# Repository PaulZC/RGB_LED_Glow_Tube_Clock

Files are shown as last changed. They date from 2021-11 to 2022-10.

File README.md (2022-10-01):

# RGB LED Glow Tube Clock

A drop-in replacement PCB for one of the popular LED "Nixie" Glow Tube Clocks available through the usual suppliers.

Features:

* ESP32 WROOM processor - uses WiFi to obtain network time from an NTP server
* 60 x WS2812-2020 2mm x 2mm RGB LEDs - to illuminate the engraved acrylic glow tube digits
* VEML7700 ambient light (lux) sensor - the lux can be used to adjust the LED brightness
* USB-C interface - for 5V power and firmware updates

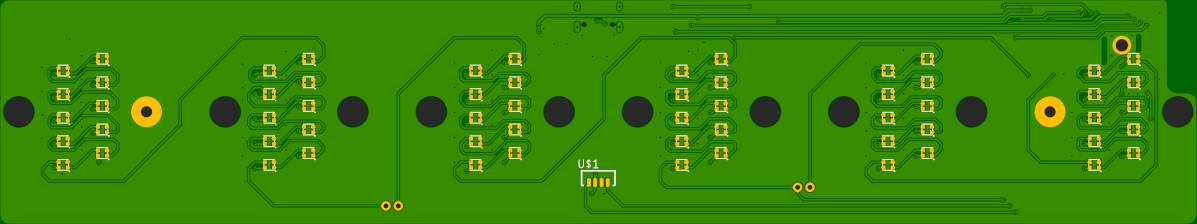
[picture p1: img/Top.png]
Pictured is the top of the circuit board


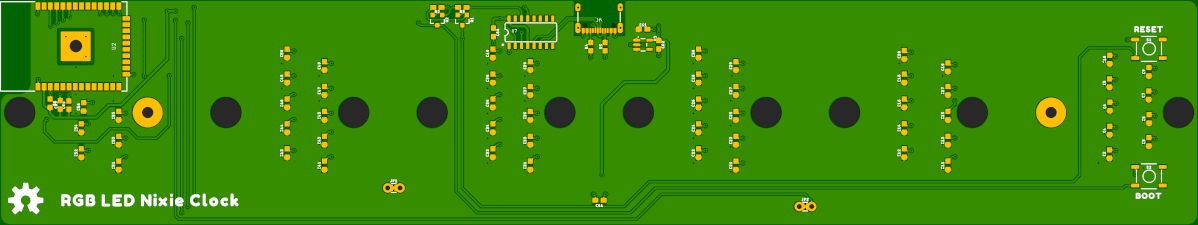
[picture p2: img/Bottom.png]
Pictured is the bottom of the circuit board


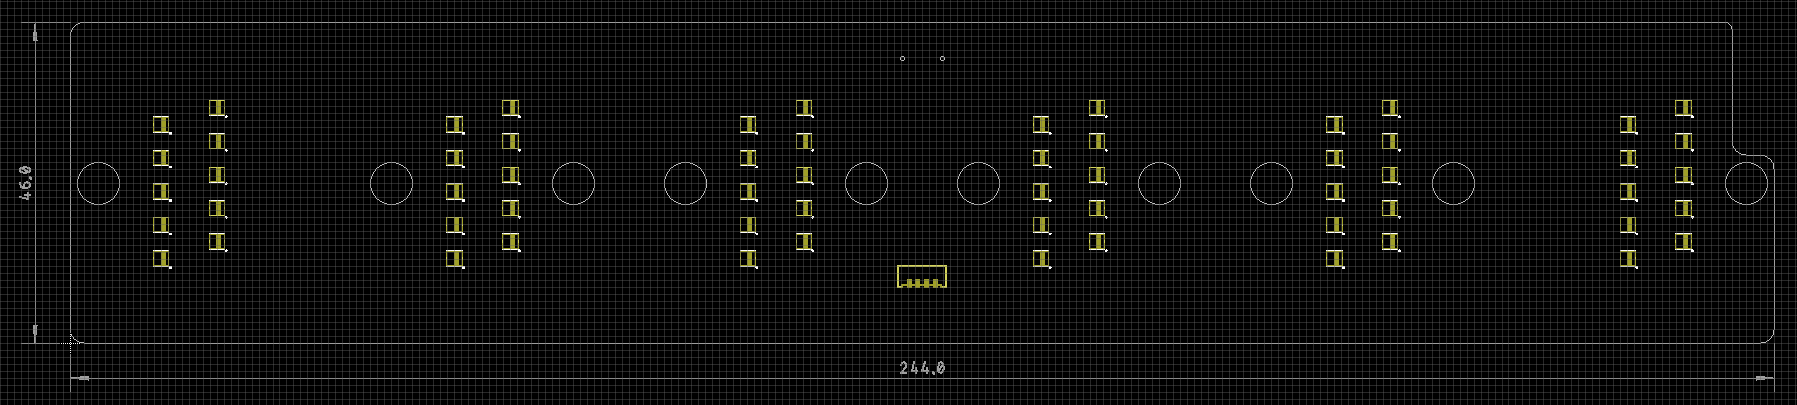
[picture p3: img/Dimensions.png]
Pictured are the circuit board dimensions


Enjoy!

**_Paul_**

## Licence

Please see [LICENSE.md](./LICENSE.md) for details.

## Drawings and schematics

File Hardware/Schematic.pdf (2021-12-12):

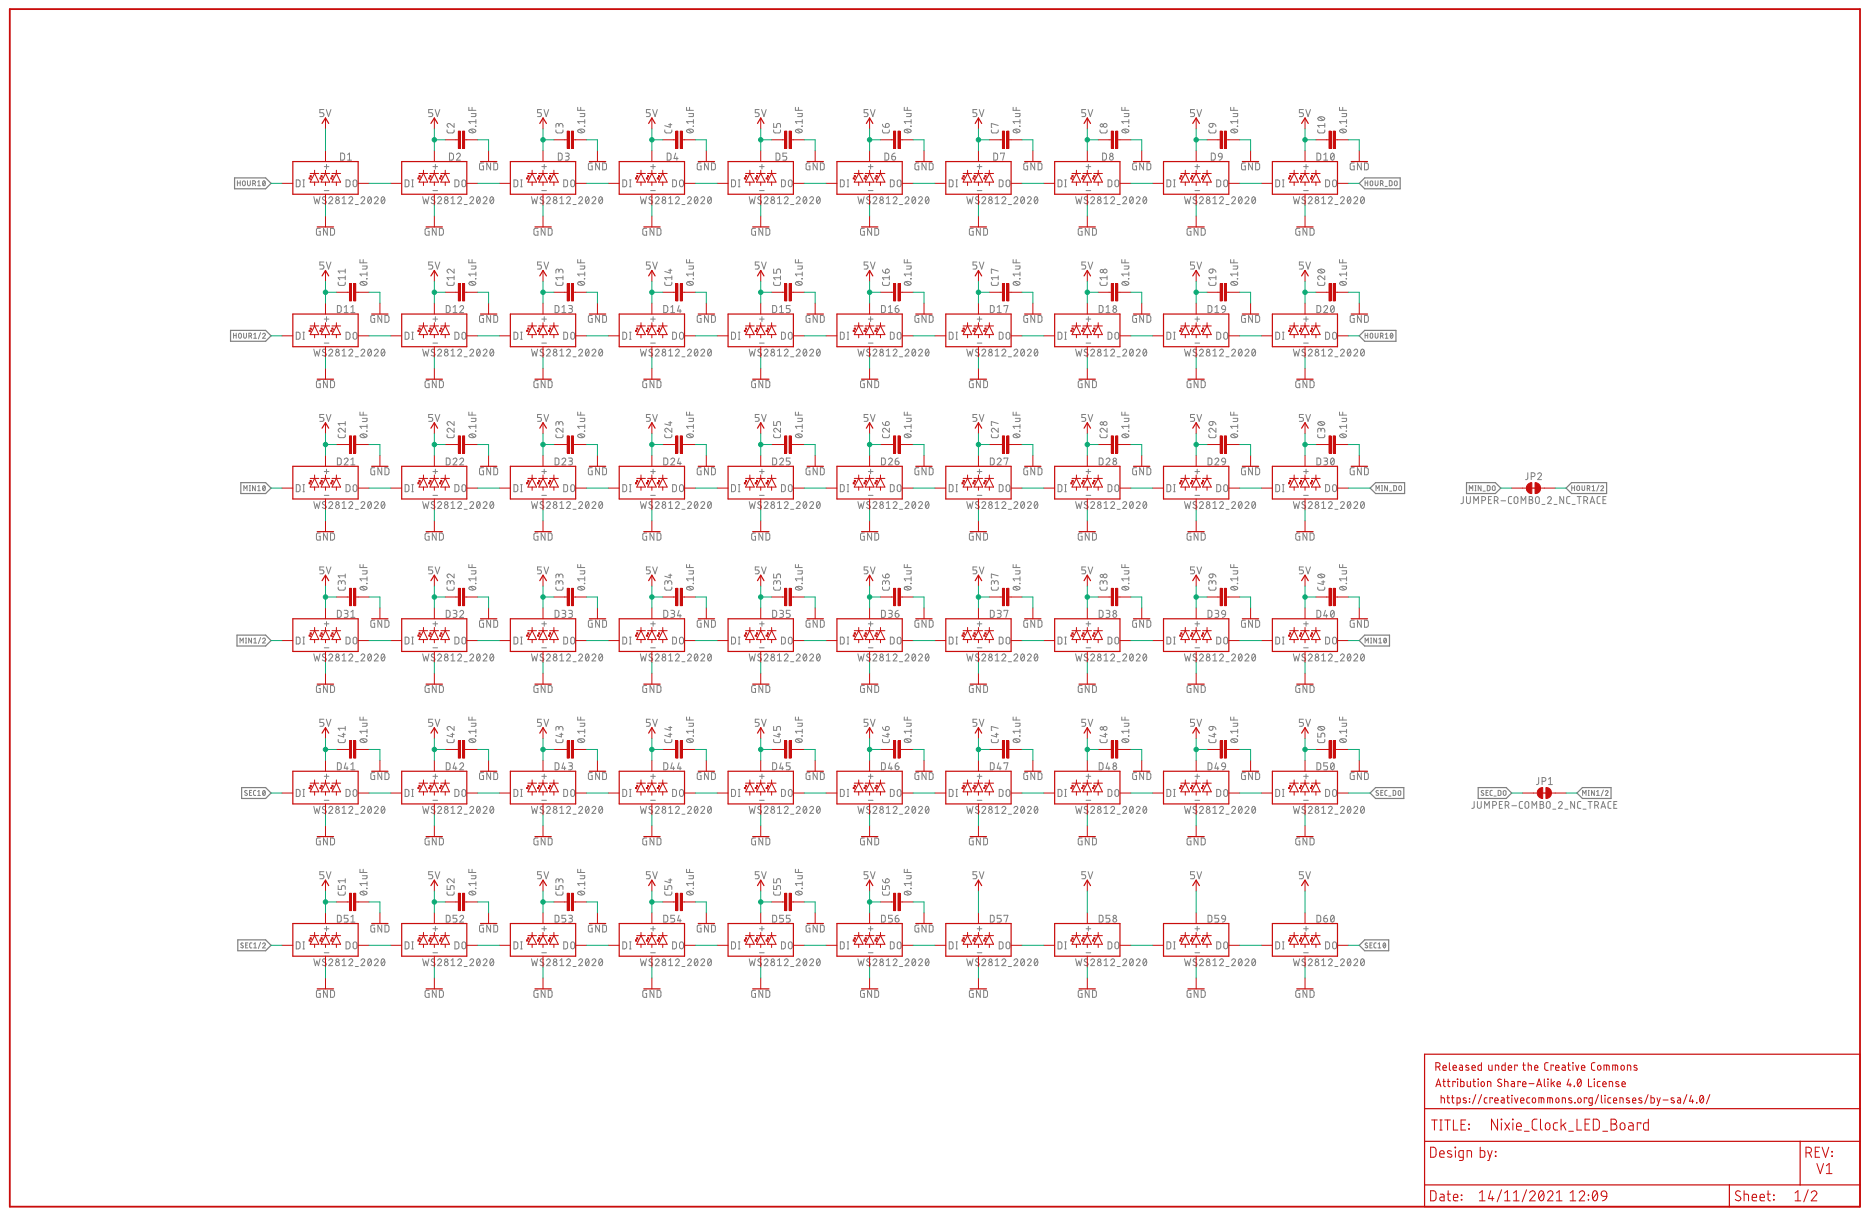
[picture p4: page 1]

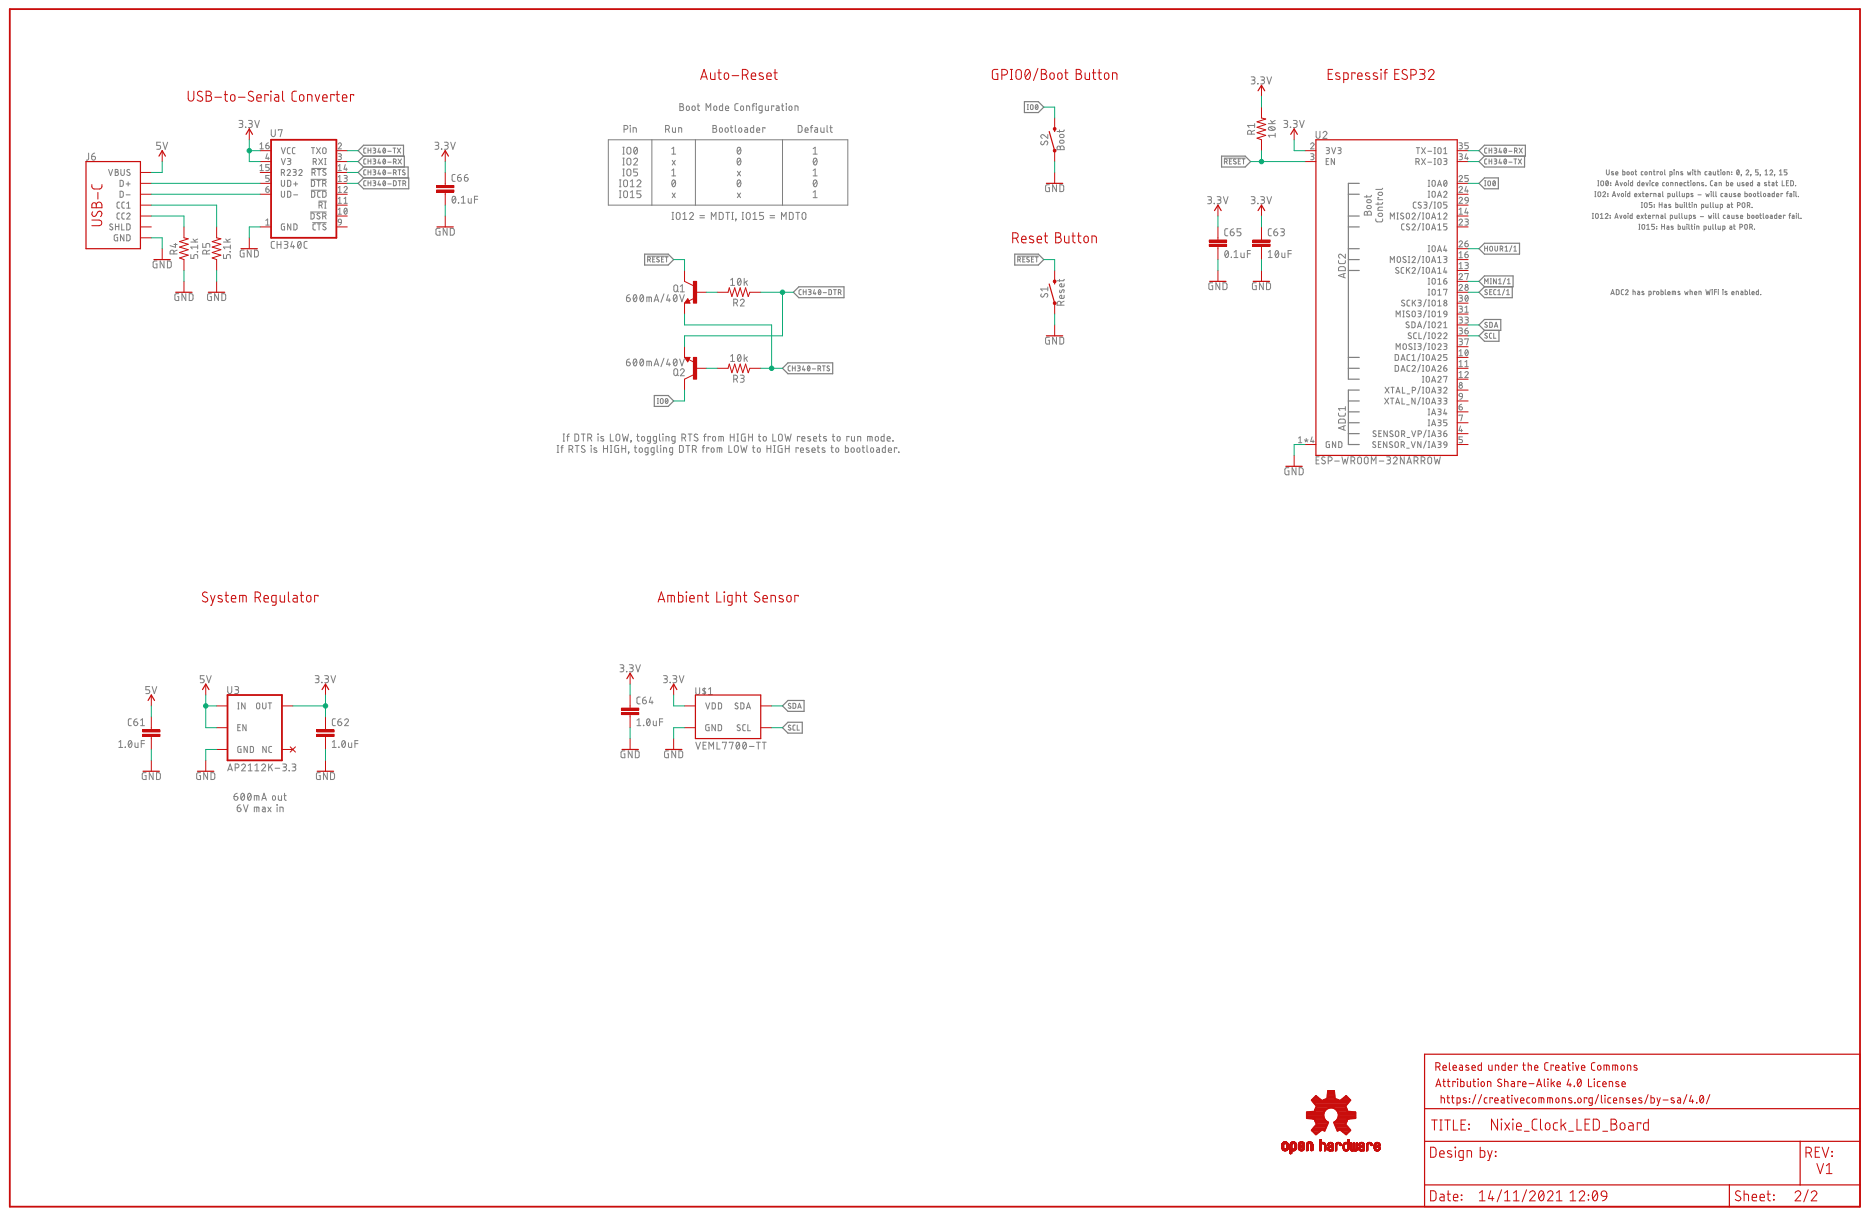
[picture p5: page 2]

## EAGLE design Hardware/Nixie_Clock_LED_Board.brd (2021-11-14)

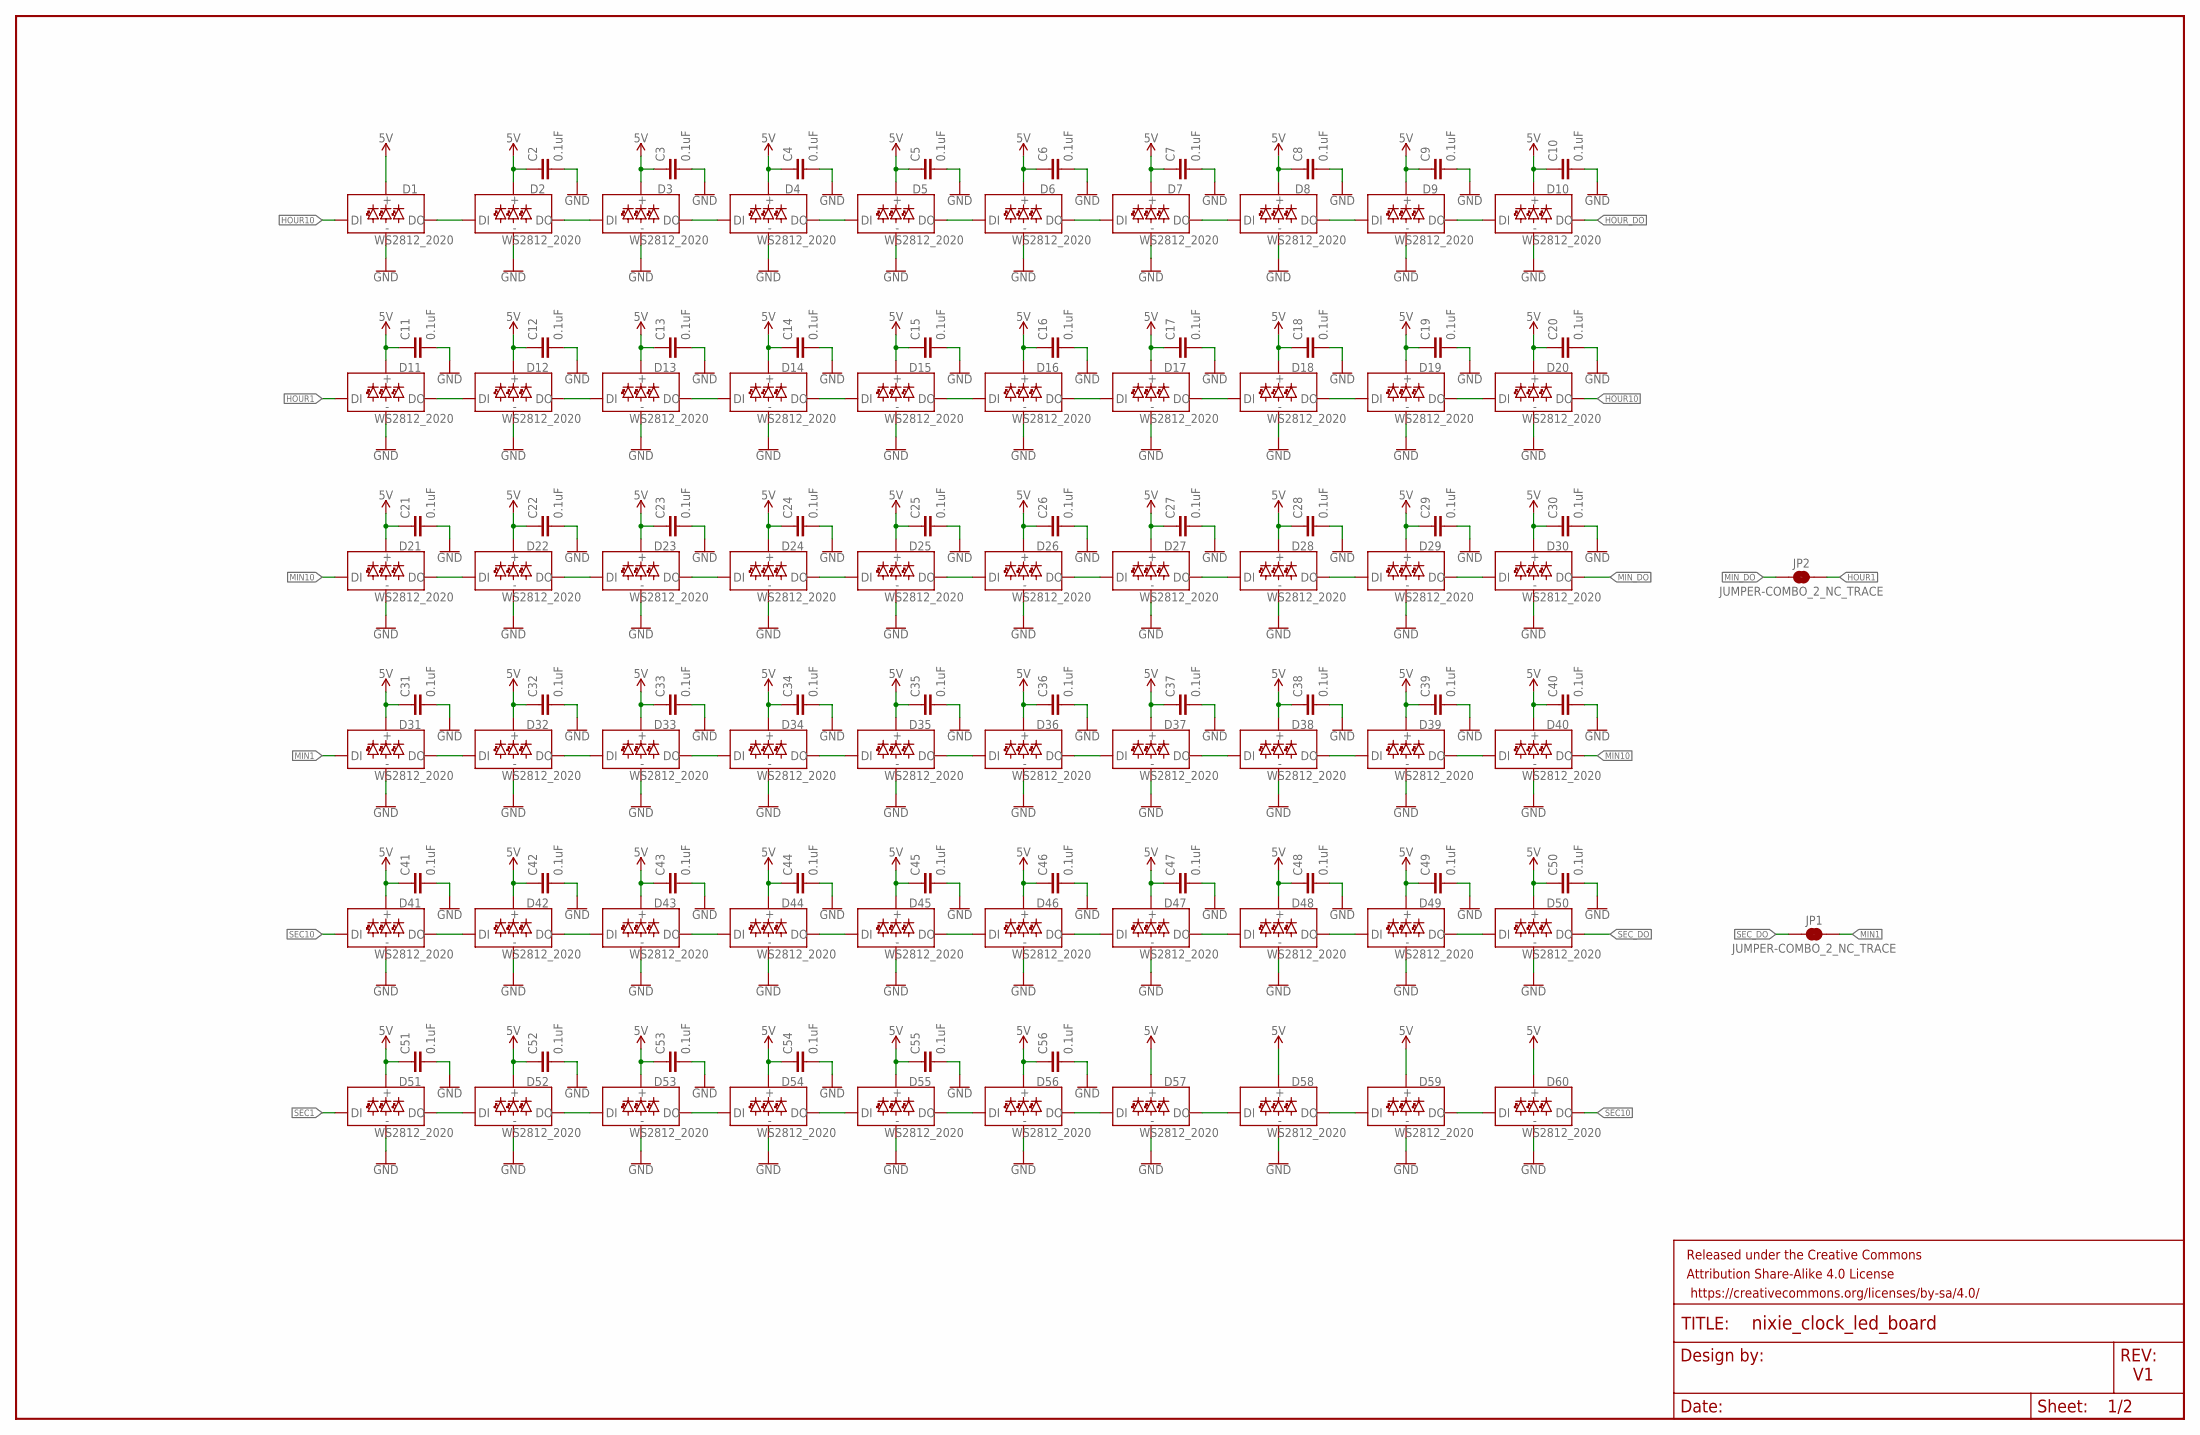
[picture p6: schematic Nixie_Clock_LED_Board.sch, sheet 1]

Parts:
C2, C3, C4, C5, C6, C7, C8, C9, C10, C11, C12, C13, C14, C15, C16, C17, C18, C19, C20, C21, C22, C23, C24, C25, C26, C27, C28, C29, C30, C31, C32, C33, C34, C35, C36, C37, C38, C39, C40, C41, C42, C43, C44, C45, C46, C47, C48, C49, C50, C51, C52, C53, C54, C55, C56: 0.1uF; 0603
D1, D2, D3, D4, D5, D6, D7, D8, D9, D10, D11, D12, D13, D14, D15, D16, D17, D18, D19, D20, D21, D22, D23, D24, D25, D26, D27, D28, D29, D30, D31, D32, D33, D34, D35, D36, D37, D38, D39, D40, D41, D42, D43, D44, D45, D46, D47, D48, D49, D50, D51, D52, D53, D54, D55, D56, D57, D58, D59, D60: WS2812_2020; WS2812-2020
FRAME2: FRAME-LEDGER; CREATIVE_COMMONS
JP1, JP2: JUMPER-COMBO_2_NC_TRACE; COMBO-JUMPER_2_NC_TRACE

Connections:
5V: C2.1, C3.1, C4.1, C5.1, C6.1, C7.1, C8.1, C9.1, C10.1, C11.1, C12.1, C13.1, C14.1, C15.1, C16.1, C17.1, C18.1, C19.1, C20.1, C21.1, C22.1, C23.1, C24.1, C25.1, C26.1, C27.1, C28.1, C29.1, C30.1, C31.1, C32.1, C33.1, C34.1, C35.1, C36.1, C37.1, C38.1, C39.1, C40.1, C41.1, C42.1, C43.1, C44.1, C45.1, C46.1, C47.1, C48.1, C49.1, C50.1, C51.1, C52.1, C53.1, C54.1, C55.1, C56.1, D1.VCC, D2.VCC, D3.VCC, D4.VCC, D5.VCC, D6.VCC, D7.VCC, D8.VCC, D9.VCC, D10.VCC, D11.VCC, D12.VCC, D13.VCC, D14.VCC, D15.VCC, D16.VCC, D17.VCC, D18.VCC, D19.VCC, D20.VCC, D21.VCC, D22.VCC, D23.VCC, D24.VCC, D25.VCC, D26.VCC, D27.VCC, D28.VCC, D29.VCC, D30.VCC, D31.VCC, D32.VCC, D33.VCC, D34.VCC, D35.VCC, D36.VCC, D37.VCC, D38.VCC, D39.VCC, D40.VCC, D41.VCC, D42.VCC, D43.VCC, D44.VCC, D45.VCC, D46.VCC, D47.VCC, D48.VCC, D49.VCC, D50.VCC, D51.VCC, D52.VCC, D53.VCC, D54.VCC, D55.VCC, D56.VCC, D57.VCC, D58.VCC, D59.VCC, D60.VCC; also elsewhere on the board
GND: C2.2, C3.2, C4.2, C5.2, C6.2, C7.2, C8.2, C9.2, C10.2, C11.2, C12.2, C13.2, C14.2, C15.2, C16.2, C17.2, C18.2, C19.2, C20.2, C21.2, C22.2, C23.2, C24.2, C25.2, C26.2, C27.2, C28.2, C29.2, C30.2, C31.2, C32.2, C33.2, C34.2, C35.2, C36.2, C37.2, C38.2, C39.2, C40.2, C41.2, C42.2, C43.2, C44.2, C45.2, C46.2, C47.2, C48.2, C49.2, C50.2, C51.2, C52.2, C53.2, C54.2, C55.2, C56.2, D1.GND, D2.GND, D3.GND, D4.GND, D5.GND, D6.GND, D7.GND, D8.GND, D9.GND, D10.GND, D11.GND, D12.GND, D13.GND, D14.GND, D15.GND, D16.GND, D17.GND, D18.GND, D19.GND, D20.GND, D21.GND, D22.GND, D23.GND, D24.GND, D25.GND, D26.GND, D27.GND, D28.GND, D29.GND, D30.GND, D31.GND, D32.GND, D33.GND, D34.GND, D35.GND, D36.GND, D37.GND, D38.GND, D39.GND, D40.GND, D41.GND, D42.GND, D43.GND, D44.GND, D45.GND, D46.GND, D47.GND, D48.GND, D49.GND, D50.GND, D51.GND, D52.GND, D53.GND, D54.GND, D55.GND, D56.GND, D57.GND, D58.GND, D59.GND, D60.GND; also elsewhere on the board
HOUR1: D11.DI, JP2.2, JP2.4 (2); also elsewhere on the board
HOUR10: D1.DI, D20.DO
HOUR_DO: D10.DO
MIN1: D31.DI, JP1.2, JP1.4 (2); also elsewhere on the board
MIN10: D21.DI, D40.DO
MIN_DO: D30.DO, JP2.1, JP2.3 (1)
unnamed: D1.DO, D2.DI
unnamed: D2.DO, D3.DI
unnamed: D3.DO, D4.DI
unnamed: D4.DO, D5.DI
unnamed: D5.DO, D6.DI
unnamed: D6.DO, D7.DI
unnamed: D7.DO, D8.DI
unnamed: D8.DO, D9.DI
unnamed: D9.DO, D10.DI
unnamed: D11.DO, D12.DI
unnamed: D12.DO, D13.DI
unnamed: D13.DO, D14.DI
unnamed: D14.DO, D15.DI
unnamed: D15.DO, D16.DI
unnamed: D16.DO, D17.DI
unnamed: D17.DO, D18.DI
unnamed: D18.DO, D19.DI
unnamed: D19.DO, D20.DI
unnamed: D41.DO, D42.DI
unnamed: D21.DO, D22.DI
unnamed: D22.DO, D23.DI
unnamed: D23.DO, D24.DI
unnamed: D24.DO, D25.DI
unnamed: D25.DO, D26.DI
unnamed: D26.DO, D27.DI
unnamed: D27.DO, D28.DI
unnamed: D28.DO, D29.DI
unnamed: D29.DO, D30.DI
unnamed: D31.DO, D32.DI
unnamed: D32.DO, D33.DI
unnamed: D33.DO, D34.DI
unnamed: D34.DO, D35.DI
unnamed: D35.DO, D36.DI
unnamed: D36.DO, D37.DI
unnamed: D37.DO, D38.DI
unnamed: D38.DO, D39.DI
unnamed: D39.DO, D40.DI
unnamed: D42.DO, D43.DI
unnamed: D43.DO, D44.DI
unnamed: D44.DO, D45.DI
unnamed: D45.DO, D46.DI
unnamed: D46.DO, D47.DI
unnamed: D47.DO, D48.DI
unnamed: D48.DO, D49.DI
unnamed: D49.DO, D50.DI
unnamed: D51.DO, D52.DI
unnamed: D52.DO, D53.DI
unnamed: D53.DO, D54.DI
unnamed: D54.DO, D55.DI
unnamed: D55.DO, D56.DI
unnamed: D56.DO, D57.DI
unnamed: D57.DO, D58.DI
unnamed: D58.DO, D59.DI
unnamed: D59.DO, D60.DI
SEC1: D51.DI; also elsewhere on the board
SEC10: D41.DI, D60.DO
SEC_DO: D50.DO, JP1.1, JP1.3 (1)

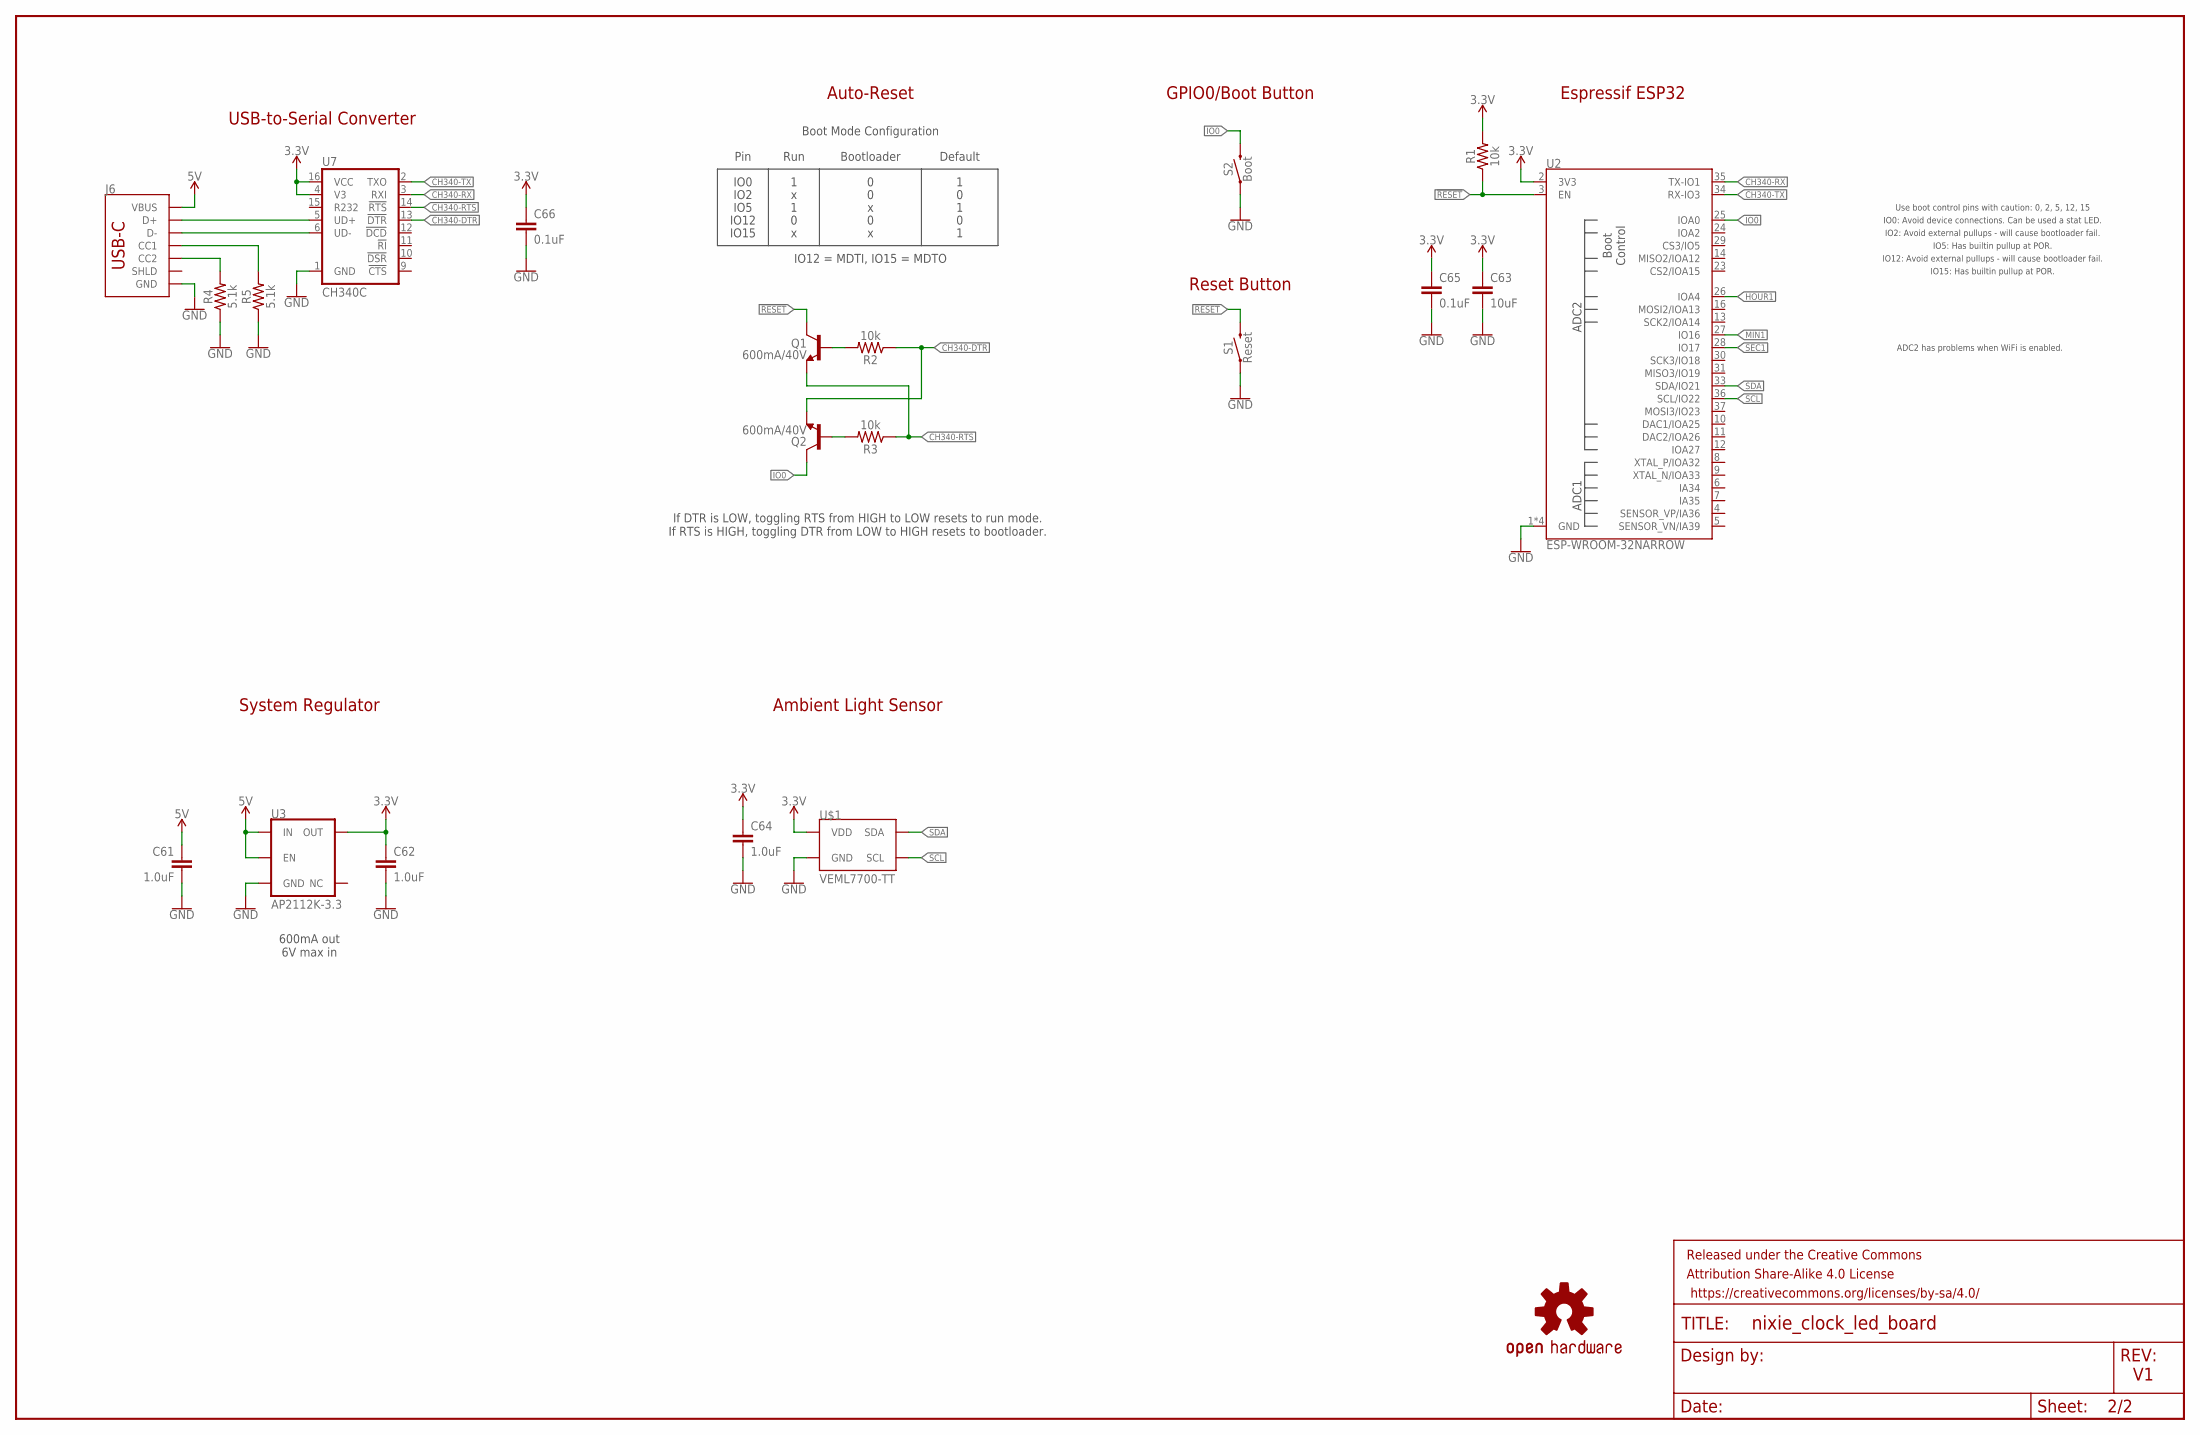
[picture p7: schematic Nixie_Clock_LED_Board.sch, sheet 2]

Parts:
C61, C62, C64: 1.0uF; 0603
C63: 10uF; 0603
C65, C66: 0.1uF; 0603
FRAME1: FRAME-LEDGER; CREATIVE_COMMONS
J6: USB_C_2-LAYER_PADS; USB-C-16P-2LAYER-PADS
LOGO2: OSHW-LOGOL; OSHW-LOGO-L
Q1, Q2: 600mA/40V; SOT23-3
R1, R2, R3: 10k; 0603
R4, R5: 5.1k; 0603
S1: Reset; TACTILE_SWITCH_SMD_5.2MM
S2: Boot; TACTILE_SWITCH_SMD_5.2MM
U2: ESP-WROOM-32NARROW; ESP-WROOM-32-NARROW
U3: AP2112K-3.3; SOT23-5
U7: CH340C; SO016
U$1: VEML7700-TT; VEML7700_TT

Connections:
3.3V: C62.1, C63.1, C64.1, C65.1, C66.1, R1.2, U2.2 (3V3), U3.5 (OUT), U7.4 (V3), U7.16 (VCC), U$1.2 (VDD)
5V: C61.1, J6.VBUS1 (VBUS), J6.VBUS2 (VBUS), U3.1 (IN), U3.3 (EN); also elsewhere on the board
!RESET!: Q1.3 (C), R1.1, S1.3 (2), U2.3 (EN)
CH340-DTR: Q2.2 (E), R2.1, U7.13 (!DTR)
CH340-RTS: Q1.2 (E), R3.1, U7.14 (!RTS)
CH340-RX: U2.35 (TX-IO1), U7.3 (RXI)
CH340-TX: U2.34 (RX-IO3), U7.2 (TXO)
D+: J6.A6 (D+), J6.B6 (D+), U7.5 (UD+)
D-: J6.A7 (D-), J6.B7 (D-), U7.6 (UD-)
GND: C61.2, C62.2, C63.2, C64.2, C65.2, C66.2, J6.GND, J6.GND2 (GND), R4.1, R5.1, S1.1, S2.1, U2.1 (GND), U2.15 (GND), U2.38 (GND), U2.GND, U3.2 (GND), U7.1 (GND), U$1.3 (GND); also elsewhere on the board
HOUR1: U2.26 (IOA4); also elsewhere on the board
IO0: Q2.3 (C), S2.3 (2), U2.25 (IOA0)
MIN1: U2.27 (IO16); also elsewhere on the board
unnamed: Q2.1 (B), R3.2
unnamed: Q1.1 (B), R2.2
unnamed: J6.B5 (CC2), R4.2
unnamed: J6.A5 (CC1), R5.2
SCL: U2.36 (SCL/IO22), U$1.1 (SCL)
SDA: U2.33 (SDA/IO21), U$1.4 (SDA)
SEC1: U2.28 (IO17); also elsewhere on the board

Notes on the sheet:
USB-to-Serial Converter
System Regulator
600mA out 6V max in
Auto-Reset
Espressif ESP32
Reset Button
If DTR is LOW, toggling RTS from HIGH to LOW resets to run mode. If RTS is HIGH, toggling DTR from LOW to HIGH resets to bootloader.
GPIO0/Boot Button
Pin
IO0
IO2
IO12
IO15
IO5
Run
Bootloader
Default
IO12 = MDTI, IO15 = MDTO
Boot Mode Configuration
IO0: Avoid device connections. Can be used a stat LED.
ADC2 has problems when WiFi is enabled.
IO12: Avoid external pullups - will cause bootloader fail.
Use boot control pins with caution: 0, 2, 5, 12, 15
IO2: Avoid external pullups - will cause bootloader fail.
IO15: Has builtin pullup at POR.
IO5: Has builtin pullup at POR.
Ambient Light Sensor

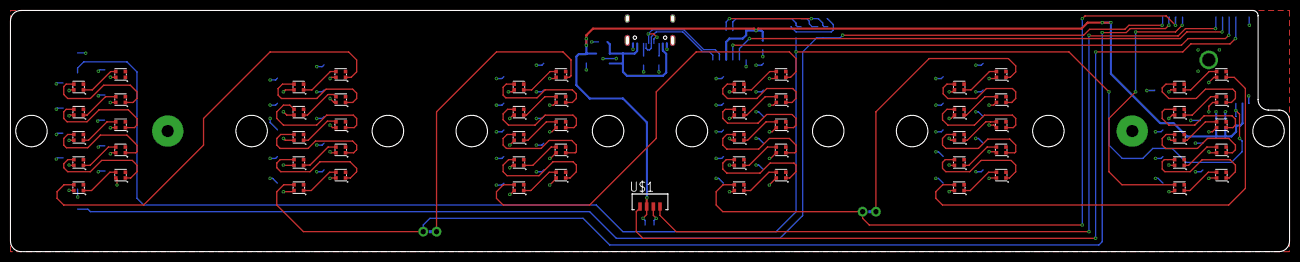
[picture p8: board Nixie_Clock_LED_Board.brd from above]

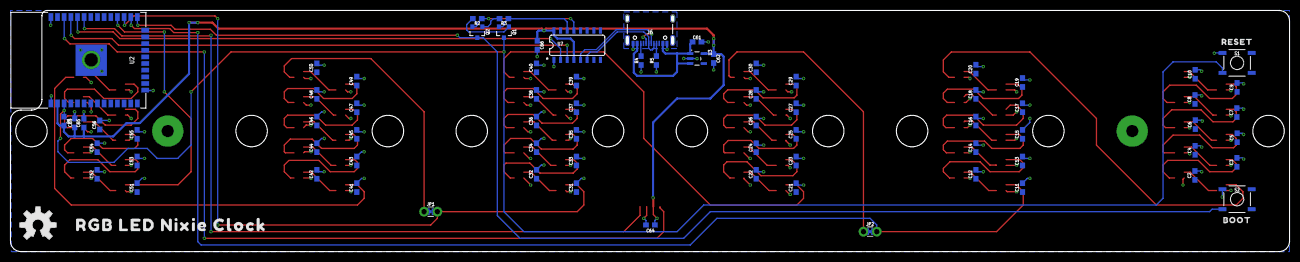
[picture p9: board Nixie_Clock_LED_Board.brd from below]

Board: 2 copper layers, 244.0 x 46.0 mm, 143 parts (80 on the bottom side), 79 nets.

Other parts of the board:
U$2: RESET0
U$3: BOOT0
U$4: RGB_LED_NIXIE_CLOCK0

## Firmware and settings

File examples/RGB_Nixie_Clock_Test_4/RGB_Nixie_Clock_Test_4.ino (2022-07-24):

// ESP32 WROOM RGB LED Nixie Clock Test - use the VEML7700 to adjust the LED brightness

//=-=-=-=-=-=-=-=-=-=-=-=-=-=-=-=-=-=-=-=-=-=-=-=-=-=-=-=-=-=-=-=-=-=-=-=-=-=-=-=-=-=-=-=-=

#include <WiFi.h>
#include "time.h"
#include "sntp.h"
#include "secrets.h"

//=-=-=-=-=-=-=-=-=-=-=-=-=-=-=-=-=-=-=-=-=-=-=-=-=-=-=-=-=-=-=-=-=-=-=-=-=-=-=-=-=-=-=-=-=

const char* ntpServer1 = "europe.pool.ntp.org"; // The Network Time Protocol Server
const char* ntpServer2 = "time.nist.gov";
const char* timeZoneRule = "GMT0BST,M3.5.0/1,M10.5.0"; // https://github.com/esp8266/Arduino/blob/master/cores/esp8266/TZ.h

//=-=-=-=-=-=-=-=-=-=-=-=-=-=-=-=-=-=-=-=-=-=-=-=-=-=-=-=-=-=-=-=-=-=-=-=-=-=-=-=-=-=-=-=-=

#include <FastLED.h> // http://librarymanager/All#FastLED

#define LED_PIN     17 //GPIO17 on ESP32 WROOM is connected to SEC_1 WS2812 LED
#define COLOR_ORDER GRB
#define CHIPSET     WS2812
#define NUM_LEDS    60

#define maxBrightness 255
#define minBrightness 25
int brightness = maxBrightness;

CRGB leds[NUM_LEDS];

//=-=-=-=-=-=-=-=-=-=-=-=-=-=-=-=-=-=-=-=-=-=-=-=-=-=-=-=-=-=-=-=-=-=-=-=-=-=-=-=-=-=-=-=-=

#include <SparkFun_VEML7700_Arduino_Library.h> // Click here to get the library: http://librarymanager/All#SparkFun_VEML7700

VEML7700 mySensor; // Create a VEML7700 object

#define minLux 5 // The lux below which the LEDs will be at minBrightness
#define maxLux 75 // The lux at which the LEDs will reach maxBrightness
bool sensorOnline;

//=-=-=-=-=-=-=-=-=-=-=-=-=-=-=-=-=-=-=-=-=-=-=-=-=-=-=-=-=-=-=-=-=-=-=-=-=-=-=-=-=-=-=-=-=

void setup() {
  
  delay(1000);
  
  FastLED.addLeds<CHIPSET, LED_PIN, COLOR_ORDER>(leds, NUM_LEDS).setCorrection( TypicalLEDStrip );
  FastLED.setBrightness( brightness );
  FastLED.clear(true); // Turn all the LEDs off

  Serial.begin(115200);
  Serial.println(F("RGB LED Nixie Clock"));

  Wire.begin(21, 22); // Tell Wire which pins to use (the SparkFun ESP32 Thing Plus defaults to 23 and 22)
  sensorOnline = mySensor.begin();
  if (sensorOnline == false)
  {
    Serial.println("Unable to communicate with the VEML7700!");
    timeToLEDs(99, 99, 99);
    FastLED.show();
    delay(1000);
    FastLED.clear(true); // Turn all the LEDs off
    FastLED.show();
  }
  else
  {
    setBrightness();
  }

  setClock();

}

void loop()
{
  static uint8_t lastSecs = 0;
  
  // getLocalTime stalls for several seconds if the RTC has not been set (using NTP)
  // Use gettimeofday instead (and manually convert to tm)
  struct timeval tv;
  struct timezone tz;
  gettimeofday(&tv, &tz);
  time_t t = (time_t)tv.tv_sec;
  struct tm *timeinfo;
  timeinfo = localtime(&t);

  if (lastSecs != timeinfo->tm_sec)
  {
    Serial.println(timeinfo, "%A, %B %d %Y %H:%M:%S");

    if ((timeinfo->tm_hour == 1) && (timeinfo->tm_min == 0) && (timeinfo->tm_sec == 0)) // Resync the clock at 1AM
    //if (timeinfo->tm_sec == 0) // Resync the clock every minute - for testing
    {
      setClock();
    }
    else if ((timeinfo->tm_min % 15 == 0) && (timeinfo->tm_sec == 0)) // Set the LED brightness every 15 mins
    //else if (timeinfo->tm_sec %10 == 0) // Set the LED brightness every 10 seconds - for testing
    {
      setBrightness();
    }
    else
    {
      timeToLEDs(timeinfo->tm_hour, timeinfo->tm_min, timeinfo->tm_sec);
    }
    lastSecs = timeinfo->tm_sec;
  }
  
  FastLED.show();

  delay(20);
}

void setClock()
{
  FastLED.clear(true); // Turn all the LEDs off
  FastLED.show();

  //=-=-=-=-=-=-=-=-=-=-=-=-=-=-=-=-=-=-=-=-=-=-=-=-=-=-=-=-=-=-=-=-=-=-=-=-=-=-=-=-=-=-=-=-=
  // Configure SNTP

  // set notification call-back function
  sntp_set_time_sync_notification_cb( timeavailable );

  sntp_set_sync_interval(15000); // Set the NTP sync interval to 15s (the minimum)
  
  /**
   * A more convenient approach to handle TimeZones with daylightOffset 
   * would be to specify a environmnet variable with TimeZone definition including daylight adjustmnet rules.
   * A list of rules for your zone could be obtained from https://github.com/esp8266/Arduino/blob/master/cores/esp8266/TZ.h
   */
  configTzTime(timeZoneRule, ntpServer1, ntpServer2);    

  /**
   * NTP server address could be aquired via DHCP,
   *
   * NOTE: This call should be made BEFORE esp32 aquires IP address via DHCP,
   * otherwise SNTP option 42 would be rejected by default.
   * NOTE: configTime() function call if made AFTER DHCP-client run
   * will OVERRIDE aquired NTP server address
   */
  sntp_servermode_dhcp(1);    // (optional)

  //=-=-=-=-=-=-=-=-=-=-=-=-=-=-=-=-=-=-=-=-=-=-=-=-=-=-=-=-=-=-=-=-=-=-=-=-=-=-=-=-=-=-=-=-=
  // Connect to WiFi.

  Serial.print(F("Connecting to local WiFi"));

  WiFi.begin(ssid, password);

  unsigned long startTime = millis();
  
  while ((WiFi.status() != WL_CONNECTED) && (millis() < (startTime + 20000))) // Timeout after 20 seconds
  {
    delay(500);
    Serial.print(F("."));
  }
  Serial.println();

  if (millis() >= (startTime + 15000))
  {
    WiFi.disconnect(true);
    WiFi.mode(WIFI_OFF);
    Serial.println(F("WiFi connection timed out!"));
    return;
  }

  Serial.println(F("WiFi connected"));

  printLocalTime();

  //=-=-=-=-=-=-=-=-=-=-=-=-=-=-=-=-=-=-=-=-=-=-=-=-=-=-=-=-=-=-=-=-=-=-=-=-=-=-=-=-=-=-=-=-=
  // Disconnect the WiFi as it's no longer needed

  WiFi.disconnect(true);
  WiFi.mode(WIFI_OFF);
  Serial.println(F("WiFi disconnected"));  
}

// Callback function (gets called when time is adjusted via NTP)
// (Does not get called if time is not adjusted...)
void timeavailable(struct timeval *t)
{
  Serial.print("NTP Callback: ");
  printLocalTime();
}

void printLocalTime()
{
  //=-=-=-=-=-=-=-=-=-=-=-=-=-=-=-=-=-=-=-=-=-=-=-=-=-=-=-=-=-=-=-=-=-=-=-=-=-=-=-=-=-=-=-=-=
  // Set and print the RTC network time. (Code taken from the SimpleTime example.)

  struct tm timeinfo;
  if(getLocalTime(&timeinfo, 20000)) // Wait for up to 20s for time to be set (i.e. > the 15 second NTP sync interval)
  {
    Serial.println(&timeinfo, "Network time is: %A, %B %d %Y %H:%M:%S");
  }
  else
  {
    Serial.println("No time available (yet)");
  }
}

void timeToLEDs(uint8_t hour, uint8_t min, uint8_t sec)
{
  //Set the hue to the fraction of day.
  uint8_t hue = (uint8_t)(((((float)(((uint32_t)(hour * 60 * 60)) + ((uint32_t)(min * 60)) + ((uint32_t)(sec)))) / 86400.0)) * 256.0);

  //Apply the rainbow to the LEDs
  fill_rainbow( leds, NUM_LEDS, hue, 4); // 256 / 60 = 4 (approx.)

  // Change the other LEDs to Black
  for (int i = 0; i < 60; i++)
  {
    if ((i != 00 + (sec % 10))
    &&  (i != 10 + (sec / 10))
    &&  (i != 20 + (min % 10))
    &&  (i != 30 + (min / 10))
    &&  (i != 40 + (hour % 10))
    &&  (i != 50 + (hour / 10)))
      leds[i] = CRGB::Black;
  }
}

void setBrightness()
{
  FastLED.clear(true); // Turn all the LEDs off
  FastLED.show();

  if (!sensorOnline) // Return now if the VEML7700 is offline
    return;
    
  delay(500); // Wait for half a second for the VEML7700 to settle

  // Read the lux four times and average it
  float lux = 0.0;
  for (int i = 0; i < 4; i++)
  {
    lux += mySensor.getLux();
    delay(125);
  }
  lux /= 4.0;
  Serial.print("Lux is ");
  Serial.println(lux);

  // Now scale brightness
  if (lux <= minLux)
  {
    brightness = minBrightness;
  }
  else if (lux >= maxLux)
  {
    brightness = maxBrightness;
  }
  else
  {
    lux = (lux - minLux) / (maxLux - minLux); // Convert lux to a fraction of the lux range
    brightness = minBrightness;
    brightness += (int)((float)(maxBrightness - minBrightness) * lux);
    if (brightness > maxBrightness)
      brightness = maxBrightness;
  }
  Serial.print("Brightness is ");
  Serial.println(brightness);

  FastLED.setBrightness( brightness );
}

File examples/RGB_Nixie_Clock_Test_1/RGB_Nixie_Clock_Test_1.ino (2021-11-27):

// ESP32 WROOM RGB LED Nixie Clock Test

#include <FastLED.h> // http://librarymanager/All#FastLED

#define LED_PIN     17 //GPIO17 on ESP32 WROOM is connected to SEC_1 WS2812 LED
#define COLOR_ORDER GRB
#define CHIPSET     WS2812
#define NUM_LEDS    60

#define BRIGHTNESS  50

CRGB leds[NUM_LEDS];

uint8_t gHue = 0; // rotating "base color" used by many of the patterns

void setup() {
  delay(30); // sanity delay
  FastLED.addLeds<CHIPSET, LED_PIN, COLOR_ORDER>(leds, NUM_LEDS).setCorrection( TypicalLEDStrip );
  FastLED.setBrightness( BRIGHTNESS );
}

void loop()
{
  fill_rainbow( leds, NUM_LEDS, gHue, 4); // 256 / 60 = 4 (approx.)
  FastLED.show();
  
  EVERY_N_MILLISECONDS( 25 ) { gHue++; } // cycle the "base color" through the rainbow
}

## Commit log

2021-12-12 Add example 3 - use the lux to adjust the LED brightness
2021-12-12 Add README and PCB dimensions
2021-12-12 Add schematic and PCB images

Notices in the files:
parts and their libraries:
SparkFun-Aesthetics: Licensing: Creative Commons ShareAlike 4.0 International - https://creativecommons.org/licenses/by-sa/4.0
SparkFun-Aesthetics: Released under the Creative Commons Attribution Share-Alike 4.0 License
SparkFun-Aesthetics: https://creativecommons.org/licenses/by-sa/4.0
